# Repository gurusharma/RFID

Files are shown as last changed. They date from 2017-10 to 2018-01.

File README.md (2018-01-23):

# RFID
RFID Reader Project
# Build Instructions for RFID Reader Project

## Table of Contents
1. [Introduction](#introduction)
2. [Bill of Materials](#bill-of-materials)
3. [Time Commitment](#time-commitment)
4. [Mechanical Assembly](#mechanical-assembly)
5. [PCB or Soldering](#pcb-or-soldering)
6. [Power Up](#power-up)
7. [Unit Testing](#unit-testing)
8. [Production Testing](#production-testing)
9. [Reproducible](#reproducible)

### Introduction
On this page, you will find the instructions for building your own project on Raspberry Pi 2 utilizing RFID Serial tag reader. This project can be used to identify different RFID tags. RFID tag readers are already used in many applications, such as automatic user identification, robotics, inventory tracking and payment systems. This project is part of a bigger project where we plan to utilize the functionality of RFID reader to authenticate users of a shopping mall to conveniently login and browse helpline service.

##### Note: 
Please note that I will be referring to Raspberry Pi 2 as Pi occasionally. 

### Bill of Materials
You would need a budget of approximately $200.00 if you do not own or have access to any of the parts listed below. It is possible to obtain better deals, so feel free to do a little research before making a purchase. 

| Item 	| Quantity 	| Cost 	| Supplier 	|
|:---:	|:---:	|:---:	|:---:	|
| Raspberry Pi 2 (Includes USB cable connectors) 	| 1 	| Only Pi: $ 45.95; Ultimate Starter Kit: $119.95; Complete Starter Kit: $99.95; Basic Starter Kit With Power Adaptor: $59.95 	| [Cana Kit](https://www.canakit.com/raspberry-pi/raspberry-pi-kits) 	|
| RFID Card Reader and Tags 	| 1(reader) + 3(tags) 	| $ 59.99 	| [Parallax Inc](https://www.parallax.com/product/32390) 	|
| Female-Female Jumper Wires 	| 6 	| $ 3.95 * 	| [adafruit](https://www.adafruit.com/product/266) 	|
| Resistors 	| 2 	| $ 6.86 ** 	| [Amazon](https://www.amazon.com/dp/B01ERPXFZK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) 	|
| Soldering Kit (with Soldering Iron) 	| 1 	| $ 31.00 *** 	| [Amazon](https://www.amazon.ca/Primacc-Adjustable-Temperature-Controlled-Interchangeable/dp/B06XCZC4PF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) Humber Prototype Lab 	|
| 3-D Case for RFID reader 	| 1 	| $ 1.80 	| [Toronto Public Library](https://www.torontopubliclibrary.ca/using-the-library/computer-services/innovation-spaces/3D-design-print.jsp) 	|

\* Premium Female/Female Jumper Wires - 40 x 6" (you can strip wires to make individual ones)

\** Elegoo Electronics component pack with resistors, LEDs, Switch, Potentiometer for Arduino UNO, MEGA2560, Raspberry Pi

\*** Primacc Soldering Iron Kit

##### Note:
Prices may change over time and some of the prices are in USD, so, please verify before making a purchase.

### Time Commitment
This was part of a project course, divided over a period of 12 weeks, but the actual work hours spent on it were 3 to 5 hours every week. If the project is the only thing you have to do, then it should take less than a week, depending on how you divide tasks and deal with delays associated with finding and purchasing items. The table below gives an approximate time breakdown per task: 

| Tasks 	| Time Required to Finish Successfully 	|
|---	|---	|
| Look for parts and make a purchase * 	| 2 hours 	|
| Wait for delivery 	| 1 day to 1 week 	|
| Soldering and Testing Voltage Divider 	| < 1 hour 	|
| Create .stl file for custom case 3D printing 	| < 1 hour 	|
| Print the 3D case 	| ~ 2 hours 	|
| Configure the Pi and download libraries | ~ 2 hours |
| Project setup 	| < 10 minutes 	|
| Demo and Testing 	| < 30 minutes 	|

\* Less than 30 Minutes if you follow the links provided in the previous section

From the breakdown above, it is clear that the project does not take very long to complete. If you follow the instructions correctly and are dedicated, you can build your own prototype in less than a week.  

### Mechanical Assembly
The Parallax Serial RFID (Radio Frequency Identification) Card Reader (#28140) can be connected to any host microcontroller easily using only four connections. For the purpose of this project, I am using Raspberry Pi 2. There are 4 pins on the RFID reader and following table (from official documentation) lists their type and functionality: 
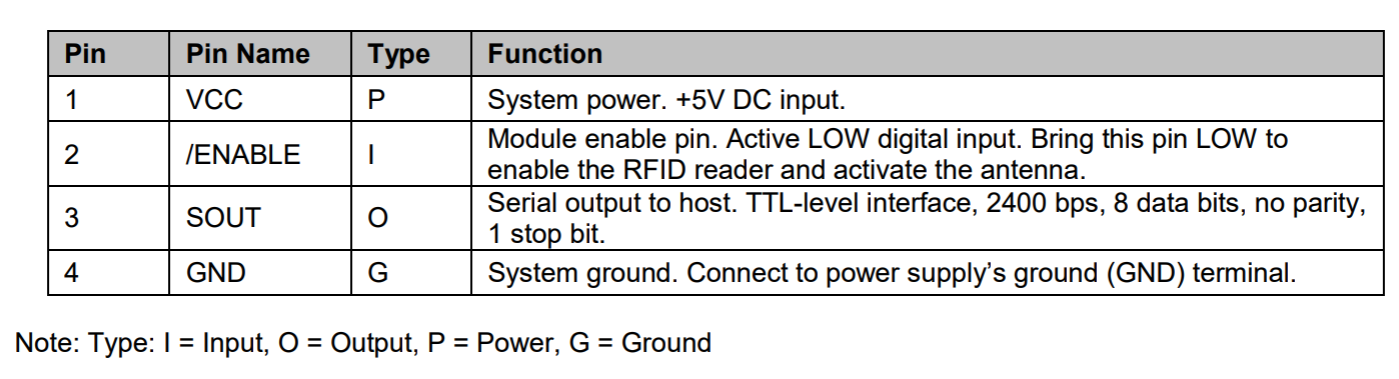
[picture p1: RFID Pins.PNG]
RFIDPins


    Figure 1: RFID Serial Card Reader's Pin Type and Functionality

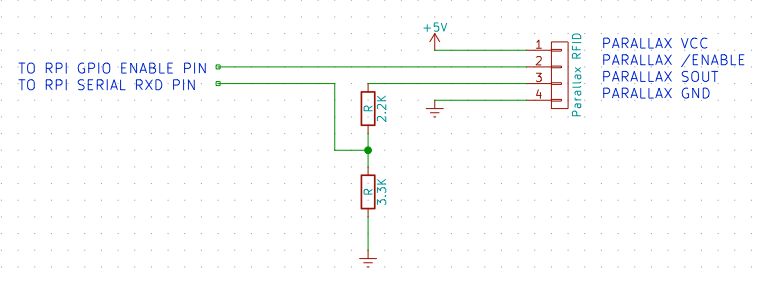
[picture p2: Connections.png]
Connections


    Figure 2: Schematic for connecting RFID Serial Card Reader to Raspberry Pi 2 

Use the schematic in Figure 2 above, to establish connections. The SOUT pin of the RFID reader is connected to a voltage divider. Use a 2200 Ω (R1) resistor and a 3300 Ω (R2) resistor to reduce 5 volts coming out of the RFID reader's SOUT to about 3 volts. This is done to avoid the risk of damaging Pi with higher voltages. You can solder these resistors along with a jumper wire to create the voltage divider as shown in the picture below (also put a heat shrink on the soldered part). Make sure you check the output of voltage divider using a multimeter before incorporating it in the assembly.

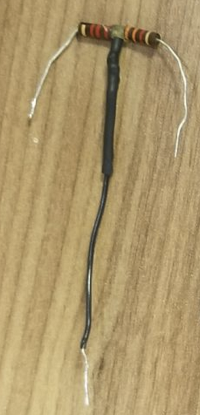
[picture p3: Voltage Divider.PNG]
VoltageDivider


     Figure 3: Voltage Divider

Now create the circuit in Figure 2; this should not take more than 10 minutes if done carefully. 

#### Linux Configuration: 
Use raspi-config to ensure that the shell is configured to run on serial port. From the main menu, select “Advanced Options” followed by “Serial”. Select “No” for the prompt to login shell over serial port. “Finish” and save configuration. Before you reboot also check that the “enable_uart” filed in “/boot/config.txt” is set equal to “1” and not “0”. Now reboot.

#### Install Python Packages: 
You may choose to program in any other language compatible with Pi. For the purpose of these build instructions, I will explain steps of programming Pi using Python. You will need to have “Python GPIO” and “Serial” packages installed. Raspberry Pi Linux distribution usually have some python packages installed. In case they are missing you can use the following commands to install it: 
```
sudo apt-get install python
sudo apt-get install python-dev
sudo apt-get install libjpeg-dev
sudo apt-get install libfreetype6-dev
sudo apt-get install python-setuptools
sudo apt-get install python-pip
```
After installing Python, you may now install above mentioned packages using: 

```
sudo pip install RPi.GPIO
sudo pip install pySerial
```
If you run into any issues with installation, follow this [link](https://jeffskinnerbox.wordpress.com/linux-python-packages-for-my-raspberry-pi/). 

#### Write a Python Script: 
You can download the script [here](https://github.com/gurusharma/RFID/blob/master/rfid.py)
and modify as needed. This script simply sets up Pi’s serial port and GPIO header. It identifies the tags being read by the reader inside a while loop. The reader reads the input tag when it is enabled low. When you run the code, it makes reader enabled low and goes into the while loop and waits for the tag to be read. It is worth knowing that the RFID tag has 12 bytes of data, the validate_rfid function ensures that the tag being read has 12 characters.      

#### Print a Case for the Sensor: 
I utilized [TINKERCAD](https://www.tinkercad.com/) to create .stl file needed for 3D printing. You may utilize the [file](https://github.com/gurusharma/RFID/blob/master/RFID%203D%20case/RFID%203D%20case.stl) I created and edit it as needed or use any other freely available online tool of your choice to do it from scratch. Once you are satisfied with .stl file, you may get it printed from any facility of your choice. If you choose to do it with Toronto Public Library, make sure to read the detailed instructions on their [website](https://www.torontopubliclibrary.ca/using-the-library/computer-services/innovation-spaces/3D-design-print.jsp). 

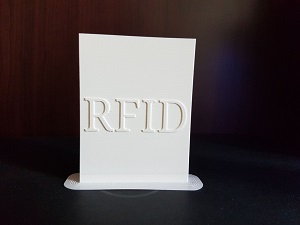
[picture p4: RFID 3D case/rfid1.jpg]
3DPrintOutput

    
    Figure 4: 3D Printed Sensor Case

##### TIP: 
The software they use for reading .stl file and printing is “CURA”, which by default tends to select the thickness of printing thread to be 0.4 mm, which usually takes more than 2 hours to finish. Make sure to change this thickness to 0.6 mm (recommended) or 0.8 mm in order to get the print done in 2 hours. In case you still have any issues, ask the staff; they are very helpful. 

### PCB or Soldering
Only soldering needed for this project is the one needed to create a voltage divider circuit. Here are the steps:
1.	Get the following parts: 
    1. two resistors R1 (2200 Ω) and R2 (3300 Ω)
    2. one jumper wire and heat shrink
    3. soldering iron
2.	Strip both ends of the wire
3.	When soldering iron is ready to use: 
    1. solder two resistors at one end and one end of the jumper wire between them 
    2. now put the heat shrink on the soldered part
    
Following these steps, you will get your voltage divider ready. Make sure to check the output voltage using a multimeter. 

### Assembly 
Now assemble all the parts as shown in the image below and put the RFID tag inside its case. Also, you may utilize any 'ground pin' for assembly.

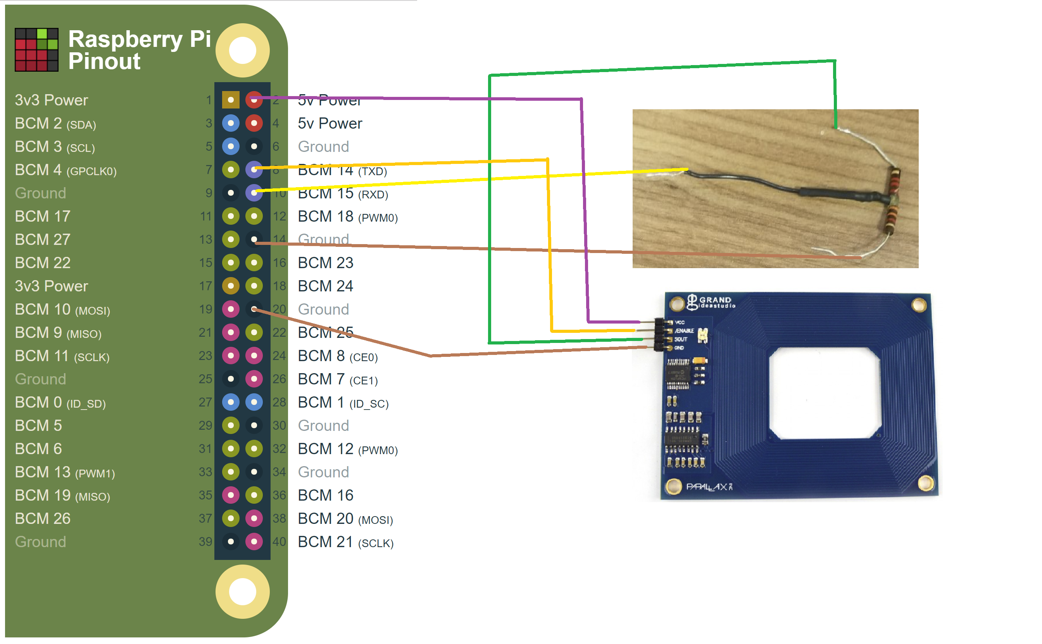
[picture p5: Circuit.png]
Circuit


    Figure 5: Circuit Assembly with Ports

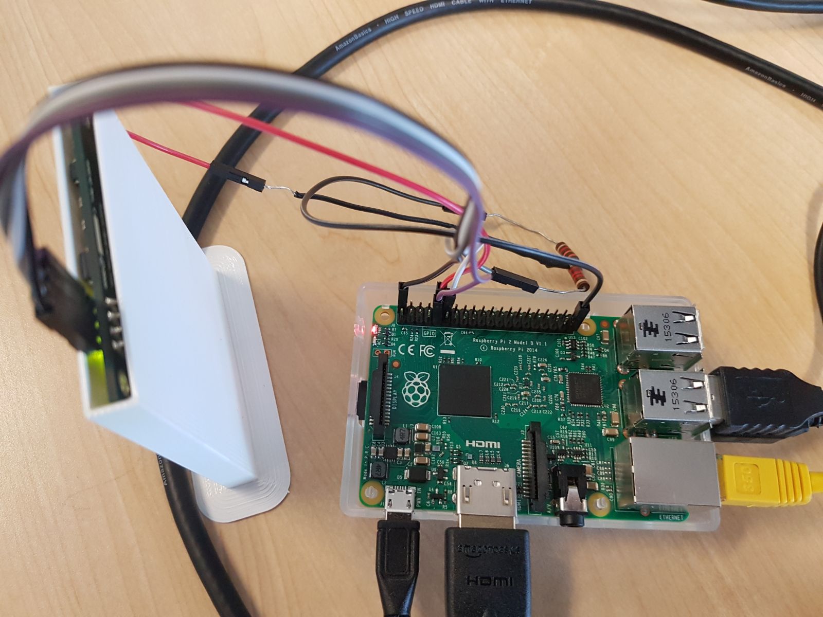
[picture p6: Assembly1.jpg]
Assembly1

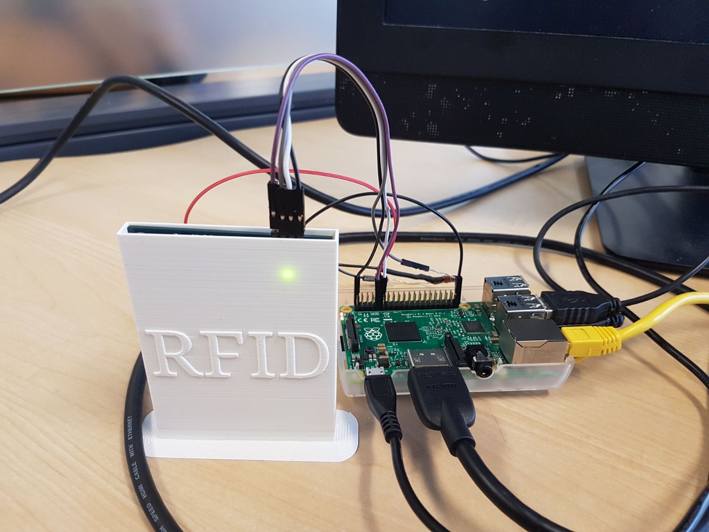
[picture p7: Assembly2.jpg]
Assembly2


    Figure 6: Complete Assembly

### Power Up
After successfully completing the tasks above, you are ready to power up. Make sure your circuit connections are correctly established; fix errors in the setup if you encounter any. Now plug the USB into Pi and connect to a computer device. In order to get the output displayed on computer, plug in the HDMI cable. Turn on the Pi. Make sure you have all the packages listed above installed in order to run the python script.

### Unit Testing
After proper setup and power up, we can now test the RFID sensor. Run the Python script using the following command: 
```
    sudo python rfid.py
```    
Now check for LED color change on RFID reader; it should turn red from green. Now you can bring one of the “world tags” closer to the reader to read. You will see the message displayed on the screen as “Welcome User #” if it was the tag belonging to a pre-registered user. If instead it was a new tag, then the message displayed would be: “Please contact admin to register first”.

### Production Testing 
If you successfully passed the unit testing, you can now go ahead with production testing. Run the python script multiple times and test different RFID tags. Check if you get the expected results. The tags are read when the LED on the reader is red (i.e. enabled low). Now your prototype is functional, you may modify the script to add more functionality.

### Reproducible
If you have the required budget and are able to follow the instructions listed above, you can easily reproduce the project and hopefully add more features to it. Happy coding and prototyping!!! All the Best!

### References
[Helpful Link](https://medium.com/@coryaspencer/using-the-parallax-serial-rfid-reader-with-the-raspberry-pi-8c948090e687)

[RFID Documentation](https://www.parallax.com/sites/default/files/downloads/28140-28340-RFID-Reader-Documentation-v2.4.pdf)

[Toronto Public Library Printing](https://www.torontopubliclibrary.ca/using-the-library/computer-services/innovation-spaces/3D-design-print.jsp)

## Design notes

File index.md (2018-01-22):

RFID Project
------------
### January 22 2018 
[Project Build instructions](https://github.com/gurusharma/RFID/blob/master/README.md) posted.

### January 15 2018  

[Presentation](https://github.com/gurusharma/RFID/blob/master/GuruPresentation.pptx) for week 11.
### January 06 2018

This is my [Progress Report](https://github.com/gurusharma/RFID/blob/master/Guru%20progress%20report.docx) for week 10.

### January 05 2018
I was not able to find a 3D case for my RFID reader on any website, so I designed it myself and got it printed from the Tornoto Public Library. Priting 3D objects at public library is very cheap but you are allowed two hours maximum for each print job. You can find printing cost and other information at this [link](http://www.torontopubliclibrary.ca/using-the-library/computer-services/innovation-spaces/3D-design-print.jsp).<br><br> I used the dimensions provided on manufacturers website to design my case. I have uploaded my design [file](https://github.com/gurusharma/RFID/blob/master/RFID%203D%20case/RFID%203D%20case.stl) in my repository. Here is how it looks after printing!!!<br><br>
RFID Reade case<br>
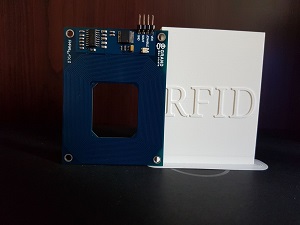
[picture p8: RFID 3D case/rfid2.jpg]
RFID Reade case
<br>
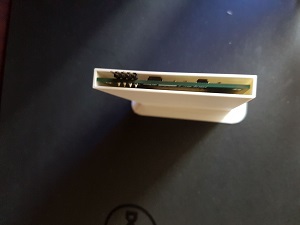
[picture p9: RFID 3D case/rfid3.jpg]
RFID Reade case
<br>
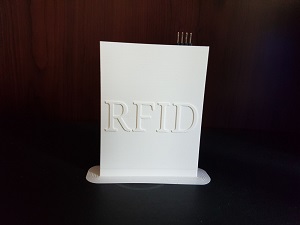
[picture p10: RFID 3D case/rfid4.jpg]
RFID Reade case
<br>

### Week 9 - December 18, 2017
30 Build videp script<br>
[Youtube](https://www.youtube.com/watch?v=5qLQqCEe3fY&feature=youtu.be)<br>

### Week 8 - December 11, 2017
### Placard
[Placard](https://github.com/gurusharma/RFID/blob/master/placard.pdf) <br>
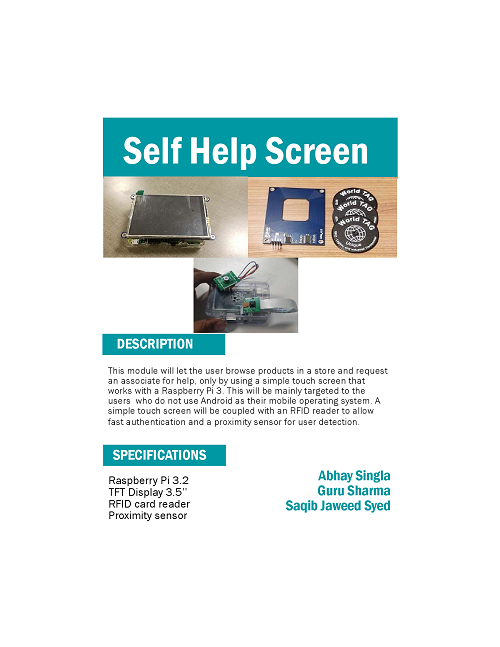
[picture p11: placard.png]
<br>
### Script
Hello my name is Guru Sharma and I am working on the RFID card reader for my project. The parts that arrived are RFID reader, RFID tags and the raspberry pi. The RFID reader module that I utilize, consists of two parts - one is RFID Reader and the other is RFID tag, with 12 digit character code in a coil. When RFID tag is placed near the RFID reader, it reads tag data serially. The transfer of data from Reader to Tag and Tag to Reader occurs with help of electromagnetic waves. For my project, I would be utilizing this technology to allow users to authenticate fast using RFID tags.

0s-10s: Opening and the parts that arived<br>
11s-20s: parts assembly and powering up sensor<br>
21s-30s: Demo of the working sensor<br>
### Week 7 - November 30, 2017
* Got all the sensors to work with my PCB board
* I started building voltage divider circuit for my sensor in order to connect my sensor with raspberry pi
### Tested LED blinking on my PCB board - November 30, 2017
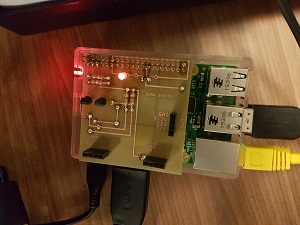
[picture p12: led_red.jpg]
<br>
Above is the picture of my PCB board with LED flashing red<br>
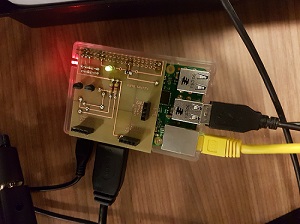
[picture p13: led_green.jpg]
<br>
Above is the picture of my PCB board with LED flashing green

### Completed soldering my PCB board - November 24, 2017
Now I am waiting for the other sensors to arrive which I will be hooking with my PCB board to read light, temperature and humidity readings

### Started working on PCB board - November 17, 2017

### Recieved Hardware parts - October 16, 2017

### Budget - October 2, 2017
[budget](https://github.com/gurusharma/RFID/blob/master/Guru_budget.xlsx)

### Gantt Chart - September 25,2017
[gantt chart](https://github.com/gurusharma/RFID/blob/master/GuruSharma.mpp)

### Proposal - September 18,2017
[proposal](https://github.com/gurusharma/RFID/blob/master/ProposalContentStudentNameRev02.xlsx)

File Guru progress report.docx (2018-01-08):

Activities versus Schedule: The project happens to be on track with the schedule. My RFID reader is working and reading data from RFID tags successfully. I have designed and printed a 3D case for my sensor.

Current Progress: I was a little worried about the functionality of the sensor after putting the case on it but I have tested it and it is working the way it should be. Over the winter break I had some extra time and I utilized it to make a PowerPoint presentation for my sensor. I have also started on the build instructions and hopefully should have them ready sometime next week.

Problems and opportunities: While trying to get my sensor to work I had issues with the python code which I got from the website I was following. I never learned python in school, so it took some extra effort from me to understand and debug the code. I have finally got it working now. Now it is reading the tag data successfully. Currently my code reads one tag at a time and detects if the card was registered before or not. After improving the code it should read more than one tags serially and have additional functionality.

Financial Status: I am on track with my financial status. I was not able to print the 3D case for sensor from college on time. So I spent $1.80 to have it printed from the Toronto Public Library.

Progress Report

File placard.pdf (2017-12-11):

# Self Help Screen

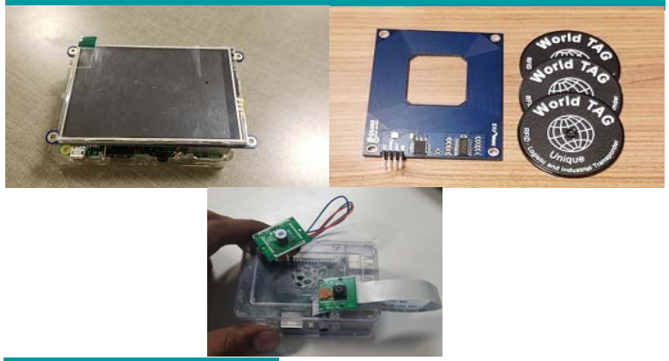
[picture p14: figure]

This module will let the user browse products in a store and request an associate for help, only by using a simple touch screen that works with a Raspberry Pi 3. This will be mainly targeted to the users who do not use Android as their mobile operating system. A simple touch screen will be coupled with an RFID reader to allow fast authentication and a proximity sensor for user detection.

### Raspberry Pi 3.2 TFT Display 3.5’’ RFID card reader Proximity sensor

## Abhay Singla Guru Sharma Saqib Jaweed Syed

## SPECIFICATIONS

## DESCRIPTION

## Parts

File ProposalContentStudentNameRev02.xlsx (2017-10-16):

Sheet: DataEntry
Submission Date | 18/912017
Project Name | Finger print scanner
Student Name | Guru Sharma
Project website | https://github.com/gurusharma/fingerprintSensor
My project will | The project will allow users to log in to the mobile app using finger print scanner
The database will store | The database store finger print ID of the users
The mobile device functionality will include | It will ask If you are a new user or already existing user. If it is a new user he will be allowed to add his finger print ID
I will be collaborating with the following company/department | Prototype lab, Humber Tech Group
My group in the winter semester will include | Guru Sharma, Abhay Singla, Saqib Jawed
50 word problem statement | Loging into a app requires users to create an account first. When you have many different user names and passwords to remember, it's hard to keep track of all of them. Using same login credentials for all accounts is a threat to acount security.
100 words of background | Everyone has marks on their fingers and they can not be removed or changed. These marks have a pattern and this pattern is called the fingerprint. Every fingerprint is special, and different from any other in the world.Phone apps that exist today require users to create login credentials before they can use it. It is easy to hack a user password that is made of character strings only. Stuides suggest that biometric scans are more safer than trditioanl passowrds. It is very hard to replicate the finger print of a user. Also logging in using fingerprint scanner is a faster and more secured proceess.
Current product APA citation | Koumaris, M. B. (2017, September 14). Arduino Fingerprint Sensor Tutorial. Retrieved September 18, 2017, from https://www.hackster.io/nickthegreek82/arduino-fingerprint-sensor-tutorial-103bb4
Existing research IEEE paper APA citation | (n.d.). Retrieved September 18, 2017, from http://ieeexplore.ieee.org/document/6146836/
Brief description of planned purchases | Raspberry Pi Fingerprint Sensor, Serial USB converter, Female-Female Jumper wires and Raspberry pi 3
Solution description | Finger print scanner offers more security and reliability to user accounts, and it's a faster way to login

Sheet: DataBase
Submission Date | Project Name | Student Name | Project website | My project will | The database will store | The mobile device functionality will include | I will be collaborating with the following company/department | My group in the winter semester will include | 50 word problem statement | 100 words of background | Current product APA citation | Existing research IEEE paper APA citation | Brief description of planned purchases | Solution description
18/912017 | Finger print scanner | Guru Sharma | https://github.com/gurusharma/fingerprintSensor | The project will allow users to log in to the mobile app using finger print scanner | Prototype lab, Humber Tech Group | It will ask If you are a new user or already existing user. If it is a new user he will be allowed to add his finger print ID | #REF! | Guru Sharma, Abhay Singla, Saqib Jawed | Loging into a app requires users to create an account first. When you have many different user names and passwords to remember, it's hard to keep track of all of them. Using same login credentials for all accounts is a threat to acount security. | Everyone has marks on their fingers and they can not be removed or changed. These marks have a pattern and this pattern is called the fingerprint. Every fingerprint is special, and different from any other in the world.Phone apps that exist today require users to create login credentials before they can use it. It is easy to hack a user password that is made of character strings only. Stuides suggest that biometric scans are more safer than trditioanl passowrds. It is very hard to replicate the finger print of a user. Also logging in using fingerprint scanner is a faster and more secured proceess. | Koumaris, M. B. (2017, September 14). Arduino Fingerprint Sensor Tutorial. Retrieved September 18, 2017, from https://www.hackster.io/nickthegreek82/arduino-fingerprint-sensor-tutorial-103bb4 | (n.d.). Retrieved September 18, 2017, from http://ieeexplore.ieee.org/document/6146836/ | Raspberry Pi Fingerprint Sensor, Serial USB converter, Female-Female Jumper wires and Raspberry pi 3 | Finger print scanner offers more security and reliability to user accounts, and it's a faster way to login

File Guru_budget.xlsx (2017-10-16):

 |  |  |  |  | Guru Sharma | N01142131
Name of Item | Description | Supplier/Part Number | Price per unit | Quantity | Taxes,Customs and Shipping | Final Total(Approximately)
CanaKit Raspberry Pi 3 Kit | Includes: Raspberry Pi 3 Model B Quad-Core 1.2 GHz 1 GB RAM, 2.5A USB Power Supply, 2 Heat Skinks and Premium case | Amazon(CanaKit) Part Number: B01GW5LUD2 | $79.99 | 1 | Taxes: $10.40, Amazon Prime free shipping | $90.40
Electronic Parts Kit | Jumper wires, resistors, capacitors,bread board, IC chips | Humber College Book Store SKU #163 | $120 | 1 | Tax: $15.6 Amazon Prime free shipping | $135.60
RFID Card Reader | SODIAL (R) USB RFID DeskTop ID Card Reader Contactless Card Reader | Amazon Part Number: 013356 | $6.59 | 1 | Tax: $0.85 Amazon Prime free shipping | $7.45
Push Button | Momentary SPST NO Red Round Cap Push Button Switch AC 6A/125V 3A/250V | Amazon Part Number: 5911 | $3.06 | 1 | Tax: $0.40 Amazon Prime free shipping | $3.40
RFID Tag | Blank Paper RFID Sticker Tag | Amazon Part Number: B01J2U3DIO | $9.99 | 1 | Tax: $1.30 Amazon Prime free shipping | $10.70
Ethernet Cable | Network Ethernet Cable | Amazon Product Number: B001TH7GVE | $6.99 | 1 | Tax: $0.91 Amazon Prime free shipping | $7.90
 |  |  |  |  | SUBTOTAL | $255.20
 |  |  |  |  | Total(need to buy) | $119.60

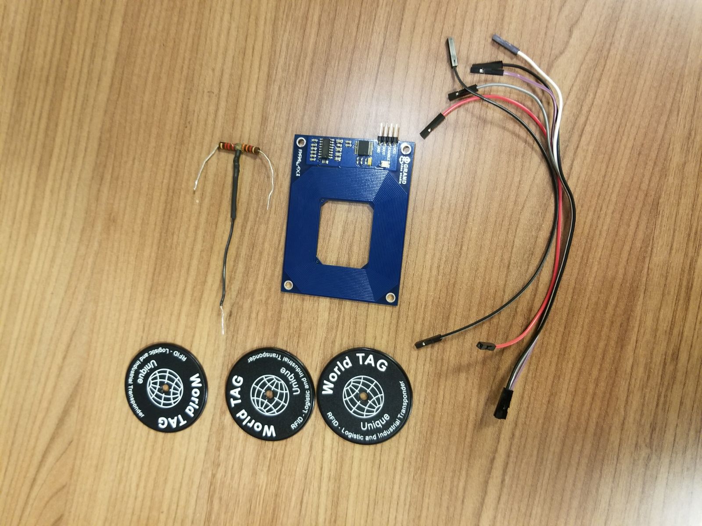
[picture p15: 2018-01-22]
Parts.jpg

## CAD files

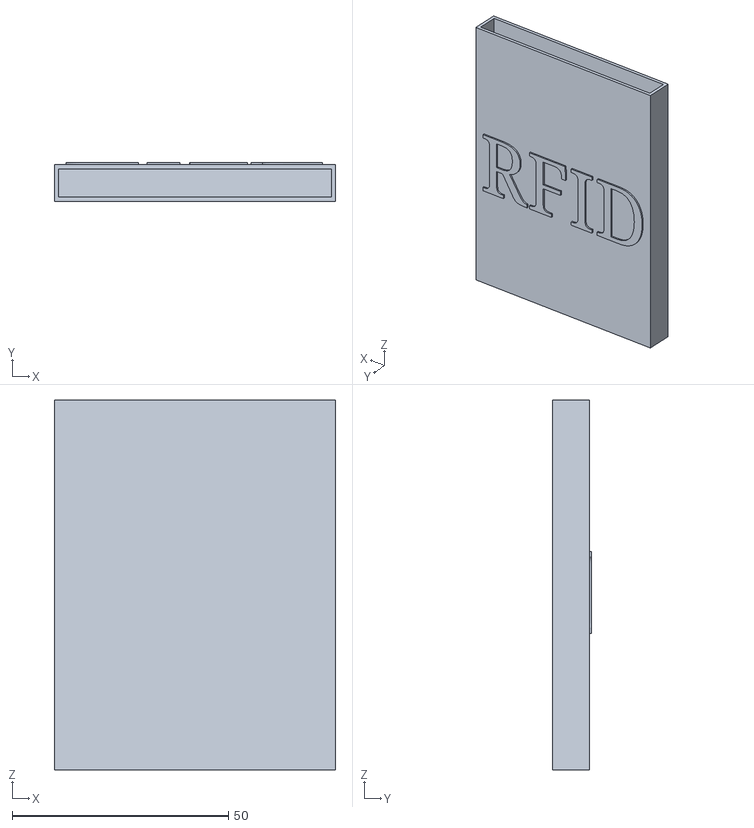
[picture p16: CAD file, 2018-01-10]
RFID 3D case/RFID 3D case.stl
65.0 x 9.00 x 85.5

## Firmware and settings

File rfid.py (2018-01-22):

#! /usr/bin/env python3

import RPi.GPIO as GPIO
import serial


ENABLE_PIN  = 18              # The BCM pin number corresponding to GPIO1

SERIAL_PORT = '/dev/ttyAMA0'  # Location of serial port.  
# This might be different depending on Operating System and version of Pi. 

                              
def validate_rfid(code):
    # The code being read is 12 characters long with the first character 
	# being a line feed and the last character being a carriage return.
    
	s = code.decode("ascii")
       
    if (len(s) == 12):
      	# return True
	
	return s[1:11] # return RFID code

    
def main():
    # Initialize the Raspberry Pi by suppressing warnings 
    GPIO.setwarnings(False)
	# Use the BCM pin numbering scheme
    GPIO.setmode(GPIO.BCM)

    # GPIO1 pin to be used to turn the RFID reader on/off
    GPIO.setup(ENABLE_PIN, GPIO.OUT)

    # Setting the pin to LOW will turn the reader on.  You should notice
    # the green LED light on the reader turn red if successfully enabled.
    print("Enabling RFID reader and reading from serial port: " + SERIAL_PORT)
    GPIO.output(ENABLE_PIN, GPIO.LOW)

    # Set up the serial port as per the Parallax reader's datasheet.
    ser = serial.Serial(baudrate = 2400,
                        bytesize = serial.EIGHTBITS,
                        parity   = serial.PARITY_NONE,
                        port     = SERIAL_PORT,
                        stopbits = serial.STOPBITS_ONE,
                        timeout  = 3)
    
	#ser = serial.Serial("/dev/ttyAMA0",baudrate=2400, timeout=5)
    
	# Wrap everything in a try block to catch any exceptions.
    try:
       var = 1
        # Loop forever, or until CTRL-C is pressed.
       while var:
            #Read in 12 byte data from serial port
            print("Reading tag...")
            data = ser.read(12)
            #print(data)
            
	        #Validate read data
            code = validate_rfid(data)
            #print(code)
            
	    #If validate_rfid() code, then check if registered or not
            if code:
                print("Read RFID code: " + code); 
		# Print message based on Tag being read
		if ("415D7D42C" in code):
			print("Welcome User1")
			var = 0
	        	GPIO.output(ENABLE_PIN, GPIO.HIGH)
		elif ("415EA0D36" in code):
			print("Welcome User2")
			var = 0
	        	GPIO.output(ENABLE_PIN, GPIO.HIGH)
		else:
			print("Please contact admin to register first")
			var = 0
	        	GPIO.output(ENABLE_PIN, GPIO.HIGH)
		
    except Exception as e:
	print (e)
        # If an exception caught, disable the reader 
		# this is done by setting the pin to HIGH
		# exit the program
        print("Disabling RFID reader...")
        GPIO.output(ENABLE_PIN, GPIO.HIGH)

        
if __name__ == "__main__":
    main()
